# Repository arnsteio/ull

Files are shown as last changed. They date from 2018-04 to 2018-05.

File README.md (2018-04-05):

*"Snorre sier at Ull kalles skiguden, bueguden, jaktguden og skjoldguden"*

# An open source, 3D-printable, reconfigurable slingbow. 

I'll post my waypoints as I progress towards the target:

## ull

Proof of concept. Standard slingshot, 3-hole BTF (Behind The Fork) tube attachment. 

## ull_v2

Same as above but decorated and with integral print support. 3-hole BTF tube attachment.
Test printed at 80% of full size, 1mm shell, 25% gradual infill. A number of issues were found and addressed.

## ull_v3 

Issues with v2 fixed. Some notes and suggestions for v4:
- If we wish to only do "thumb and brace" the handle can be 17mm shorter.
- Turn design upside down?
- Writing on surface?

v3 probably usable but haven't printed it yet. 

## ull_v4

Plain v3 but with decorations.
Have test printed: 100% size, 1mm shell, 30% constant infill, 2mm brim. 
Print went well but decorations need more work.

# Building

While a minimal test build to check structure only takes a few minutes, 
a proper test build takes an hour, and is necessary for most visuals.
And final builds take several hours. Hence, a build host apart from my 
day-to-day machine is useful.

I use git-hooks (symlinked from the /bin directory) to push to Github, 
pull to my build machine (a 4-core, 16MB Linux machine implememted on the 
UH-IaaS Openstack instance) and do builds.

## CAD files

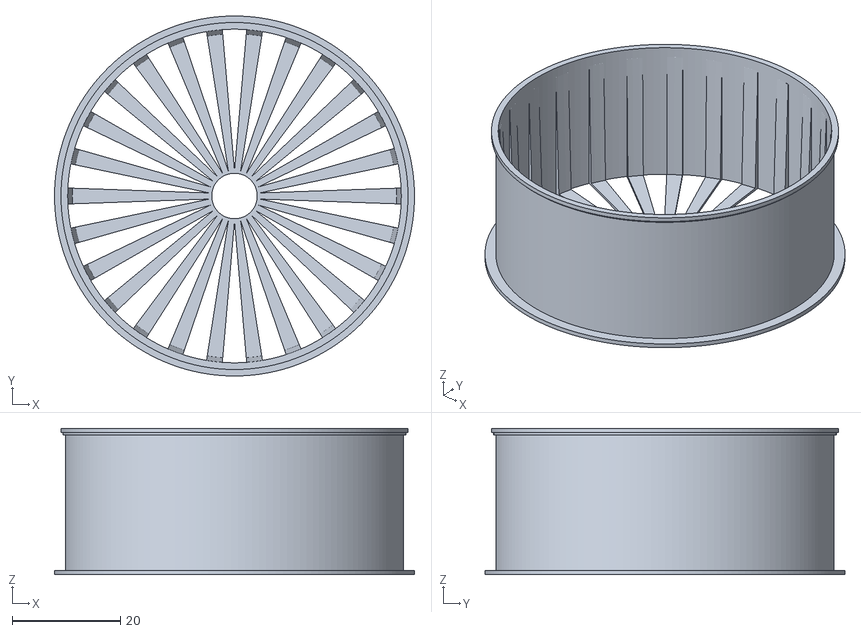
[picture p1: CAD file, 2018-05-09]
whiskerbiscuit.stl
66.5 x 66.5 x 27.0

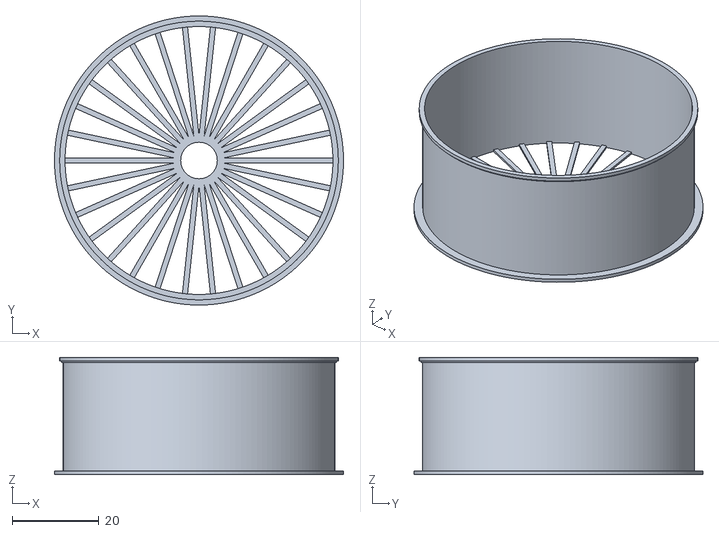
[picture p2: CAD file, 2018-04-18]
flimsy_whiskerbiscuit.stl
66.5 x 66.5 x 27.0

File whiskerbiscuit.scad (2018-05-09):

// Arnsteio, 2018

// Makes a whiskerbiscuit suitable for slingbows

/* [Global] */
slingshot_cutout_diameter=62.5; 
slingshot_thickness=25;
number_of_brushes=26; // 40 is too much, around 30 usually right
arrow_diameter=8;

$fn=150;
vres=0.15; // vertical resolution of printer
hres=0.4;  // horizontal rsolution of printer
wall_thickness=hres*1.1;

/* [Hidden] */
error=0.001;

module whiskerbiscuit(dia,width,shaft_supports, shaft_dia)
/*
Builds the whiskerbiscuit
Arguments:
    Diameter of slingbow cutout
    Thickness of slingbow
    Number of brushes that give arrow supports
    Diameter of arrow
*/
    {
    step=360/shaft_supports; // To place shaft supports evenly 

// bottom-side fastening ring
    translate([0, 0, -width/2+hres]) difference () 
        {
            //
            cylinder(h=hres*2, d=dia+4, center=true);
            cylinder(h=hres*2, d=dia, center=true);
        }
        
// top-side fastening ring
 translate([0, 0, width/2-hres]) difference () 
        {
            //
            cylinder(h=hres*2, d=dia+hres*2, center=true);
            cylinder(h=hres*2, d=dia, center=true);
        }

// Wall
    difference ()
        {
            cylinder(h=width, d=dia, center=true);
            cylinder(h=width, d=dia-wall_thickness*2, center=true);
        }
// Brushes
    difference ()
        {
            for (degrees = [0:step:360]) { // whisker biscuit "brushes"
                    rotate([0,0,degrees]) cube([dia-wall_thickness*2, hres*1.05, width], center=true);
                    }//for
                    !hull()
                    {
                        translate([0, 0, -width/4+vres*2]) resize([0,0,width/2]) sphere(d=dia-wall_thickness*2); // This gives middle bit twice the printing thickness of vres, for flexibility
                        translate([0, 0, width/2])cylinder(h=width/2, d=dia-wall_thickness*2);
                    } // hull
            cylinder(h=width, d=shaft_dia*1.05, center=true); // Cutout for shaft
        } // Brushes diff
} //Module

module flimsy_whiskerbiscuit(dia,width,shaft_supports, shaft_dia)
/*
Builds the whiskerbiscuit
Arguments:
    Diameter of slingbow cutout
    Thickness of slingbow
    Number of brushes that give arrow supports
    Diameter of arrow
*/
    {
    step=360/shaft_supports; // To place shaft supports evenly 

// BOTTOM-SIDE FASTENING RING
    translate([0, 0, -width/2+hres]) difference ()
        {
            //
            cylinder(h=hres*2, d=dia+4, center=true);
            cylinder(h=hres*2+error, d=dia-wall_thickness*2, center=true);
        }

// TOP-SIDE FASTENING RING
// Need to be above wall.
 translate([0, 0, width/2+hres*3]) difference ()
        {
            union()
            {
            cylinder(h=hres*2, d=dia+hres*2, center=true);
            translate([0,0,hres]) cylinder(h=hres*2, d=dia+hres*4, center=true);
            }
            cylinder(h=hres*4+error, d=dia-wall_thickness*2, center=true);
        }


// WALL
// Bottom-side fastening ring needs to be below wall. Ergo:
    translate([0,0,hres*2])
    difference ()
       {
        {
            // wall
            cylinder(h=width, d=dia, center=true);
            cylinder(h=width, d=dia-wall_thickness*2, center=true);
        }
       }
        
// BRUSHES
   difference () 
        {
            for (degrees = [0:step:360]) { // whisker biscuit "brushes"
                    rotate([0,0,degrees]) cube([dia-wall_thickness*2, hres*2, width], center=true);
                    rotate([0,0,degrees+1]) cube([dia-wall_thickness*2, hres*2, width], center=true);
                    rotate([0,0,degrees+2]) cube([dia-wall_thickness*2, hres*2, width], center=true);
                    rotate([0,0,degrees-1]) cube([dia-wall_thickness*2, hres*2, width], center=true);
                    rotate([0,0,degrees-2]) cube([dia-wall_thickness*2, hres*2, width], center=true);
                    }//for
            #translate([0, 0, vres*3])  cylinder(h=width, d1=dia-wall_thickness*6, d2=dia-wall_thickness*2, center=true); // makes flimsy "brushes", for flexibility
            cylinder(h=width, d=shaft_dia*1.05, center=true); // Cutout for shaft
        } // Brushes diff
} //Module

flimsy_whiskerbiscuit(slingshot_cutout_diameter, slingshot_thickness, number_of_brushes, arrow_diameter);

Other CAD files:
ull_v4.scad
ull.scad
ull_v2.scad
ull_v3.scad

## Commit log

2017-12-30 initial upload
    [vidar.scad]
2017-12-30 Trying very thin design template for teh full bslingshot body
    [vidar.scad]
2017-12-30 thin design template finished
    [vidar.scad]
2017-12-30 Build script for thin template in place
    [vidar.scad]
2017-12-30 Changed file name
    [ull.scad]
2017-12-30 deleted redundant files
    [vidar.scad]
2017-12-30 Added module for cutouts
    [ull.scad]
2017-12-30 First version of the STL
2017-12-30 Made build module Cleaned out unused modules Numerous small changes to the code Documentation for some modules finished
    [ull.scad]
2017-12-31 Added module for visual test
    [ull.scad]
2017-12-31 Cleaned some visuals, outline for support module
    [ull.scad]
2018-01-01 Added decorated version of slingshot Added link to .stl from README file
    [ull_decorated.scad]
2018-01-01 Added support to decorated.scad Compiled ull_decorated to stl Textual changes to README
    [ull_decorated.scad]
2018-01-02 Made support longer ull_decorated.scad is now not consistent with ull_decorated.stl
    [ull_decorated.scad]
2018-01-03 Updated .STL; .scd and .stl are now consistent
2018-01-03 Thicker supports might fix printing issues
    [ull_decorated.scad]
2018-01-04 Renamed a number of files Added to-do list in README (in Norwegian as that's what I had it in) Other text changes to README
    [ull_v2.scad]
2018-01-04 Started fixing some of the v2 flaws
    [ull_v3.scad]
2018-01-05 Shortened handle length Made slightly less wide Nicer fork cutout Somewhat larger band attachments Fixed band sliding slits so they are central to the holes Fixed flexible thickness
    [ull_v3.scad]
2018-01-05 Compiled the STL
    [ull_v3.scad]
2018-01-05 Small changes in .scad; had to recompile STL
    [ull_v3.scad]
2018-01-05 stl currently not printable after chacking
2018-03-24 Fixed compile issues
    [ull_v3.scad]
2018-03-26 Compile verbosity; fixed support; cleaned up code
    [ull_v3.scad]
2018-03-26 Needed shorter model - Shortened support plate - Made head shorter by 20mm
    [ull_v3.scad]
2018-03-28 Finished v3, started v4: - Cleaned up v3 code - Integrated resolution parameter with build method - Started vith v4; release for Veierland. - Added text to v4
    [ull_v3.scad, ull_v4.scad]
2018-03-30 Moved text slightly for better visuals
    [ull_v4.scad]
2018-03-30 Build file: 30% infill, 1mm shell, 2mm brim
2018-03-30 Added v4 print info
2018-04-03 Added more decorative text
    [ull_v4.scad]
2018-04-03 Typo; commented out parts of executable code I wanted built
    [ull_v4.scad]
2018-04-04 Moved text
    [ull_v4.scad]
2018-04-04 Testing different text depth
    [ull_v4.scad]
2018-04-05 Testing different letter depths
    [ull_v4.scad]
2018-04-05 Added old stl builds to gitignore
2018-04-05 Testing different letter depth
    [ull_v4.scad]
2018-04-05 Played arpund with text
    [ull_v4.scad]
2018-04-06 Testing text depth
    [ull_v4.scad]
2018-04-06 Merged manually
    [ull_v4.scad]
2018-04-07 Added whiskerbiscuit
    [ull_v4.scad, whiskerbiscuit.scad]
2018-04-08 Better whiskerbiscuit: - Added solid whiskerbiscuit as well as more "flimsy" whiskerbiscuit - Made model dependent on printer geometry
    [whiskerbiscuit.scad]
2018-04-08 Added module "flimsy_whiskerbiscuit", and built it
    [flimsy_whiskerbiscuit.stl, whiskerbiscuit.scad]
2018-04-10 Redesignes whiskerbiscuit: - Small top locking ring - Large bottom locking ring - Narrower wanes ("brushes") - Full width body
    [whiskerbiscuit.scad, whiskerbiscuit.stl]
2018-04-11 Made fork narrower to allow whickerbiscuit snap-on; Changed some fonts
    [ull_v4.scad]
2018-04-11 Miniscule text placement changes
    [ull_v4.scad]
2018-04-13 Changed flanges to move beyond walls of slingshot
    [flimsy_whiskerbiscuit.stl, whiskerbiscuit.scad]
2018-04-13 Redesign for print size, fork depth and support options - Shorter head. Important to get print size below 200mm - Deeper fork cutout. Better geometry, even more important given shorter head. - Moved 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
    [ull_v4.scad]
2018-04-13 Miniscule text changes
    [ull_v4.scad]
2018-04-18 Changed thickness of whiskerbiscuit brushes
    [flimsy_whiskerbiscuit.stl, whiskerbiscuit.scad]
2018-04-25 Made brushes slightly thicker
    [whiskerbiscuit.scad, whiskerbiscuit.stl]
2018-04-25 Chenged whiskerbiscuit: - After test shooting, saw we needed fatter brushes - Added support for Thingiverse's "Customizer"-API
    [whiskerbiscuit.scad]
2018-05-09 Several small design changes to the whiskerbiscuit: - Problem with too flimsy brushes addressed by making them wider at the base, closest to the sides - Problem with brushes "glueing" together addres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
    Have not printed yet but am hopeful.
    [whiskerbiscuit.scad, whiskerbiscuit.stl]
